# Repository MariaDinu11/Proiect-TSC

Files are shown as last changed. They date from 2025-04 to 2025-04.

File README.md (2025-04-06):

# Proiect-TSC

  OpenBook E-Reader
OpenBook este un e-book reader open source si accesibil, proiectat pentru a oferi o experiență bună de citire la un preț competitiv.



## Bill of Materials (BOM)

| Nr. | Componenta | Descriere | Cantitate | Link achizitie | Datasheet |
|-----|---|---|---|---|---|
| 1 | ESP32-C6-WROOM-1-N8 | Modul WiFi/Bluetooth/Zigbee | 1 | [Model](https://www.snapeda.com/parts/ESP32-C6-WROOM-1-N8/Espressif+Systems/view-part/?ref=eda) | [Datasheet](https://www.espressif.com/sites/default/files/documentation/esp32-c6_datasheet_en.pdf) |
| 2 | W25Q512JVEIQ | Memorie Flash NOR 64MB | 1 | [Model](https://www.snapeda.com/parts/W25Q512JVEIQ/Winbond+Electronics/view-part/?ref=eda) | [Datasheet](https://www.winbond.com/resource-files/W25Q512JV%20RevI%2005132020%20Plus.pdf) |
| 3 | DS3231SN# | Modul RTC de inalta precizie | 1 | [Model](https://www.snapeda.com/parts/DS3231SN%23/Analog+Devices/view-part/?ref=eda) | [Datasheet](https://datasheets.maximintegrated.com/en/ds/DS3231.pdf) |
| 4 | MAX17048G+T10 | Controlor pentru monitorizarea bateriei | 1 | [Model](https://www.snapeda.com/parts/MAX17048G+T10/Analog+Devices/view-part/?ref=eda) | [Datasheet](https://datasheets.maximintegrated.com/en/ds/MAX17048-MAX17049.pdf) |
| 5 | BME688 | Senzor integrat de mediu | 1 | [Model](https://www.snapeda.com/parts/BME680/Bosch/view-part/?welcome=home) | [Datasheet](https://www.bosch-sensortec.com/media/boschsensortec/downloads/datasheets/bst-bme688-ds000.pdf) |
| 6 | MCP73831 | Controler de incarcare baterie Li-Po | 1 | [Model](https://www.mouser.co.uk/ProductDetail/Microchip-Technology/MCP73831T-5ACI-OT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) | [Datasheet](https://ww1.microchip.com/downloads/en/DeviceDoc/20001984g.pdf) |
| 7 | BD5229G-TR | Detector de tensiune cu timp de intarziere | 1 | [Model](https://componentsearchengine.com/part-view/BD5229G-TR/ROHM%20Semiconductor) | [Datasheet](https://fscdn.rohm.com/en/products/databook/datasheet/ic/power/voltage_detector/bd52xxg-e.pdf) |
| 8 | PFMF.050.1 | Conector USB Type-C | 1 | [Model](https://www.mouser.com/ProductDetail/Amphenol-FCI/PFMF0501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) | [Datasheet](https://cdn.amphenol-cs.com/media/wysiwyg/files/drawing/pfmf.pdf) |
| 9 | USBLC6-2SC6Y | Protectie ESD pentru linii USB | 1 | [Model](https://www.snapeda.com/parts/USBLC6-2SC6Y/STMicroelectronics/view-part/?ref=eda) | [Datasheet](https://www.st.com/resource/en/datasheet/usblc6-2.pdf) |
| 10 | 112A-TAAR-R03 | Slot pentru card microSD | 1 | [Model](https://www.mouser.com/ProductDetail/Attend/112A-TAAR-R03?qs=sGAEpiMZZMsg%2By7HCF96QHhTCuZhYGBTHJ9NEpPMzZc%3D) | [Datasheet](https://www.attend.com.tw/sites/default/files/2022-05/112A-TAAR-R03.pdf) |
| 11 | FH34SRJ-24S-0.5SH | Conector pentru ecran e-paper | 1 | [Model](https://www.hirose.com/product/p/CL0684-0832-7-99) | [Datasheet](https://www.hirose.com/product/document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) |
| 12 | DMG2305UX-7 | Tranzistor MOSFET-P 20V/4.2A | 1 | [Model](https://www.diodes.com/part/view/DMG2305UX) | [Datasheet](https://www.diodes.com/assets/Datasheets/DMG2305UX.pdf) |
| 13 | SI1308EDL-T1-GE3 | Tranzistor MOSFET-N 30V/1.5A | 1 | [Model](https://www.snapeda.com/parts/SI1308EDL-T1-GE3/Vishay+Siliconix/view-part/?ref=snap) | [Datasheet](https://www.vishay.com/docs/68732/si1308edl.pdf) |
| 14 | SD0805S020S1R0 | Inductor 1.0µH | 1 | [Model](https://eu.mouser.com/ProductDetail/KYOCERA-AVX/SD0805S020S1R0?qs=jCA%252BPfw4LHbpkAoSnwrdjw%3D%3D) | [Datasheet](http://datasheets.avx.com/schottky.pdf) |
| 15 | MBR0530 | Dioda Schottky 30V/500mA | 3 | [Model](https://www.snapeda.com/parts/MBR0530/Onsemi/view-part/?ref=eda) | [Datasheet](https://www.onsemi.com/pdf/datasheet/mbr0520lt1-d.pdf) |
| 16 | PGB1010603MR | Dioda TVS pentru protectie ESD | 5 | [Model](https://www.snapeda.com/parts/PGB1010603MR/Littelfuse/view-part/?ref=eda) | [Datasheet](https://www.littelfuse.com/media?itemid=3d1e98b7-4d37-463c-9380-c56c83b11c3c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) |
| 17 | CPH3225A | Cristal RTC 32.768kHz | 1 | [Model](https://www.snapeda.com/parts/CPH3225A/Seiko+Instruments/view-part/?ref=eda) | [Datasheet](https://www.sii.co.jp/en/quartz/files/2021/03/CPH3225A_E.pdf) |
| 18 | XC6220A331MR-G | Regulator LDO de tensiune 3.3V | 1 | [Model](https://www.torexsemi.com/products/voltage-regulators/ldo-regulators/xc6220/) | [Datasheet](https://www.torexsemi.com/file/xc6220/XC6220.pdf) |
| 19 | Buton tactil | Butoane pentru Reset, Boot, Change | 3 | [Model](https://industry.panasonic.com/ww/products/industrial-devices/mechanical-components/switches/light-touch-switches/light-touch-switches/evqpuj02k) | [Datasheet](https://industry.panasonic.com/ww/components/devices/mechanical-components/switches/light-touch-switches/products/evqpuj02k) |
| 20 | LEDs SMD 0603 | LED indicator | 1 | [Model](https://www.snapeda.com/parts/KP-1608SURCK/Kingbright/view-part/?ref=search&t=LED%200603) | [Datasheet](https://www.kingbrightusa.com/images/catalog/SPEC/APHHS1608LSURKCGKC.pdf) |
| 21 | QWIIC_RIGHT_ANGLE | Conector I²C Qwiic | 1 | [Model](https://www.sparkfun.com/products/14417) | [Datasheet](https://cdn.sparkfun.com/assets/1/4/d/8/3/Qwiic_Connector_Datasheet.pdf) |
| 22 | Rezistor 10K | SMD 0402 | 12 | [Model](https://componentsearchengine.com/part-view/R0402%201%25%20100%20K%20(RC0402FR-07100KL)/YAGEO) | - |
| 23 | Rezistor 5.1K | SMD 0402 | 2 | [Model](https://www.yageo.com/en/Product/resistors) | - |
| 24 | Rezistor 2K | SMD 0402 | 1 | [Model](https://www.yageo.com/en/Product/resistors) | - |
| 25 | Rezistor 2.2 | SMD 0402 | 1 | [Model](https://www.yageo.com/en/Product/resistors) | - |
| 26 | Rezistor 200 | SMD 0402 | 1 | [Model](https://www.yageo.com/en/Product/resistors) | - |
| 27 | Rezistor 100K | SMD 0402 | 1 | [Model](https://www.yageo.com/en/Product/resistors) | - |
| 28 | Rezistor 15 | SMD 0402 | 1 | [Model](https://www.yageo.com/en/Product/resistors) | - |
| 29 | Rezistor 0.47 | SMD 0402 | 1 | [Model](https://www.yageo.com/en/Product/resistors) | - |
| 30 | Capacitor 100nF | SMD 0402 | 10 | [Model](https://componentsearchengine.com/part-view/CC0402MRX5R5BB106/YAGEO) | - |
| 31 | Capacitor 4.7µF | SMD 0402 | 5 | [Model](https://www.yageo.com/en/Product/mlcc) | - |
| 32 | Capacitor 1µF | SMD 0402 | 10 | [Model](https://www.yageo.com/en/Product/mlcc) | - |
| 33 | Capacitor 1µF/50V | SMD 0402 | 10 | [Model](https://www.yageo.com/en/Product/mlcc) | - |
| 34 | Capacitor 10µF | SMD 0402 | 1 | [Model](https://www.yageo.com/en/Product/mlcc) | - |
| 35 | Capacitor 100µF TANT | SMD CT3528 | 1 | [Model](https://a360.co/4iZy6AA) | - |
| 36 | Test pads | Puncte de testare TP20R | 17 | [Model](https://www.keyelco.com/product.cfm/product_id/1543) | - |
| 37 | SMD Solder Jumper | Jumper SMD | 1 | [Model](https://grabcad.com/library/solder-jumpers-1) | - |

## Functionalitatea Hardware

### Componente Principale

1. **Microcontroller ESP32-C6**
   - Procesor RISC-V cu 8MB Flash
   - WiFi 6 (802.11ax), Bluetooth 5, suport Zigbee si Thread
   - Management optimizat al energiei pentru durata de viata a bateriei

2. **Interfata Display E-Paper**
   - Conectata prin interfata SPI si semnale de control dedicate
   - Circuit special pentru generarea tensiunilor e-paper
   - Consum de energie aproape zero in stare statica

3. **Sistem de Stocare**
   - Flash extern 64MB (W25Q512JVEIQ) pentru fonturi si elemente UI
   - Slot card MicroSD pentru biblioteca extinsa de carti

4. **Management Energie**
   - Circuit incarcare baterie LiPo folosind MCP73831
   - Regulator de tensiune XC6220A331MR-G pentru 3.3V stabil
   - MAX17048G+T10 pentru monitorizare precisa a nivelului bateriei
   - Moduri deep sleep pentru durata extinsa de viata a bateriei

5. **Periferice Auxiliare**
   - Senzor de mediu BME688 (temperatura, umiditate, calitatea aerului)
   - Modul RTC DS3231SN de precizie inalta
   - Conector Qwiic/Stemma QT pentru expansiune
   - Trei butoane tactile pentru navigare

### Tabel detaliat al utilizarii pinilor

| Pin ESP32-C6 | Functie | Conectat la | Justificare |
|---|---|---|---|
| GPIO 0 | IO/BOOT | Buton BOOT | Pin special cu functie de Boot necesar pentru intrarea in modul de programare |
| GPIO 1 | FLASH_CS | Memorie Flash W25Q512JVEIQ | Chip Select pentru memoria Flash externa, pozitionat logic in apropierea celorlalti pini SPI |
| GPIO 2 | EN | Circuit supervisor BD5229G-TR | Semnal de Enable pentru microcontroller, controlat de supervizorul de tensiune |
| GPIO 3 | SDA | Magistrala I²C | Linie de date pentru interfata I²C care conecteaza senzorul BME688, RTC-ul si monitorul bateriei |
| GPIO 4 | SCL | Magistrala I²C | Linie de clock pentru interfata I²C, cu rezistori pull-up adecvati |
| GPIO 5 | MOSI | Interfata SPI (Flash, E-Paper, SD) | Master Out Slave In pentru comunicatiile SPI, folosit pentru toate dispozitivele SPI |
| GPIO 6 | MISO | Interfata SPI (Flash, SD) | Master In Slave Out pentru comunicatiile SPI, primeste date de la perifericele SPI |
| GPIO 7 | SCK | Interfata SPI (Flash, E-Paper, SD) | Clock pentru interfata SPI, sincronizeaza toate dispozitivele SPI |
| GPIO 8 | USB_D+ | Interfata USB | Linie de date pozitiva USB, conectata la conectorul USB-C prin protectie ESD |
| GPIO 9 | USB_D- | Interfata USB | Linie de date negativa USB, conectata la conectorul USB-C prin protectie ESD |
| GPIO 10 | EPD_CS | E-Paper Display | Chip Select pentru display-ul e-paper, activeaza comunicatia SPI cu acesta |
| GPIO 11 | SS_SD | Card SD | Chip Select pentru cardul SD, permite selectarea independenta a cardului pe magistrala SPI comuna |
| GPIO 12 | EPD_DC | E-Paper Display | Data/Command pentru e-paper, diferentiaza intre comenzi si date pe magistrala SPI |
| GPIO 13 | EPD_RST | E-Paper Display | Reset pentru e-paper, permite reinitializarea hardware a display-ului |
| GPIO 15 | INT_RTC | Modul RTC DS3231SN | Interrupt de la RTC, permite trezirea din sleep la alarme sau evenimente temporizate |
| GPIO 16 | TXD0 | UART Debug/Test | Transmit pentru UART, folosit pentru debug si diagnosticare |
| GPIO 17 | RXD0 | UART Debug/Test | Receive pentru UART, folosit pentru debug si diagnosticare |
| GPIO 18 | EPD_BUSY | E-Paper Display | Semnal Busy de la e-paper, indica cand display-ul proceseaza date |
| GPIO 19 | IO/CHANGE | Buton CHANGE | Intrare pentru butonul de schimbare a optiunilor, cu pull-up intern |
| GPIO 21-23 | Test Pads | Puncte de testare | Pini disponibili pentru testare si diagnosticare |

## Decizii si modificari de design
* Am pozitionat componentele principale conform specificatiilor pentru a asigura compatibilitatea perfecta intre dimensiunile PCB-ului si carcasa. Bateria a fost plasata in spatiul ramas disponibil.
* Am creat planuri de masa atat pe straturile superioare cat si inferioare pentru a imbunatati integritatea semnalului si a reduce zgomotul electromagnetic.
* Rutarea a fost realizata pe ambele straturi, insa am plasat traseele de putere exclusiv pe stratul superior pentru a evita utilizarea via-urilor, conform recomandarilor.
* Am modificat dimensiunile pad-urilor pentru diode la 35 x 190 mil pentru a imbunatati procesul de fabricatie si fiabilitatea contactelor electrice.
* Pentru circuitul MAX17048G+T10, am ajustat latimea pad-urilor pentru a corespunde cu latimea traseului VBAT de 0.3 mm, asigurand o rutare consecventa si un layout mai echilibrat.



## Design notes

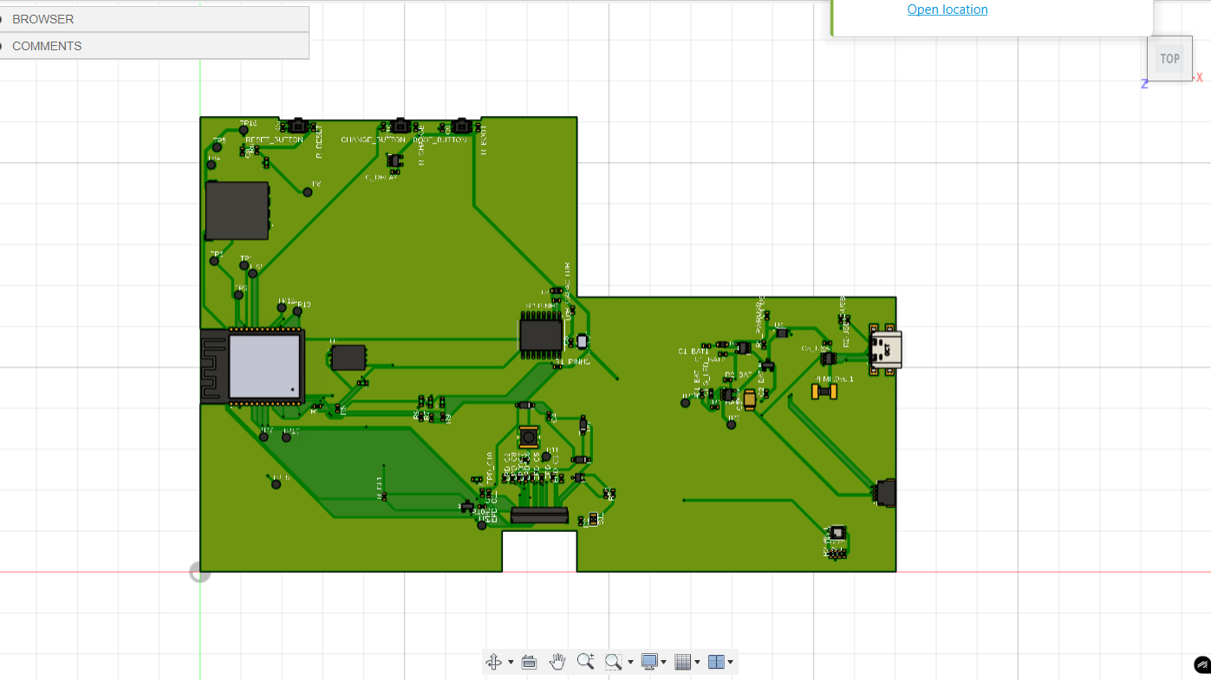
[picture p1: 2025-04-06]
Images/Screenshot 2025-04-06 195034.png

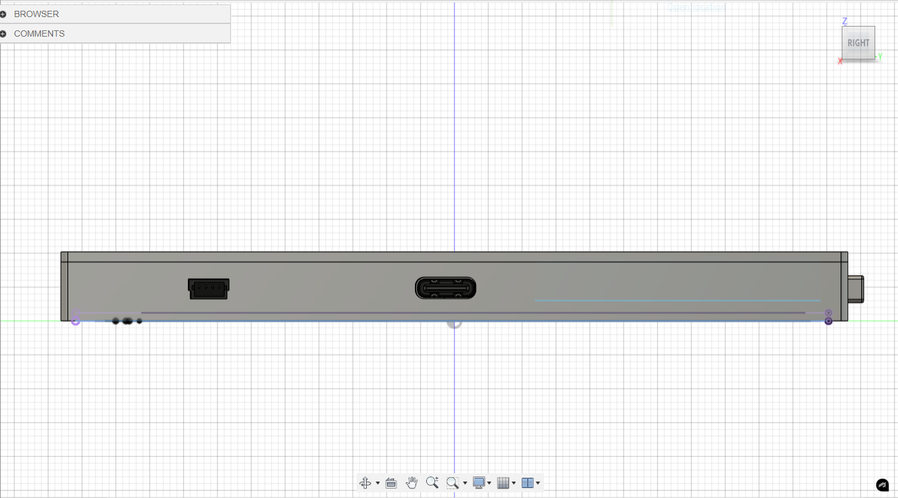
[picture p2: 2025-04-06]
Images/Screenshot 2025-04-06 195138.png

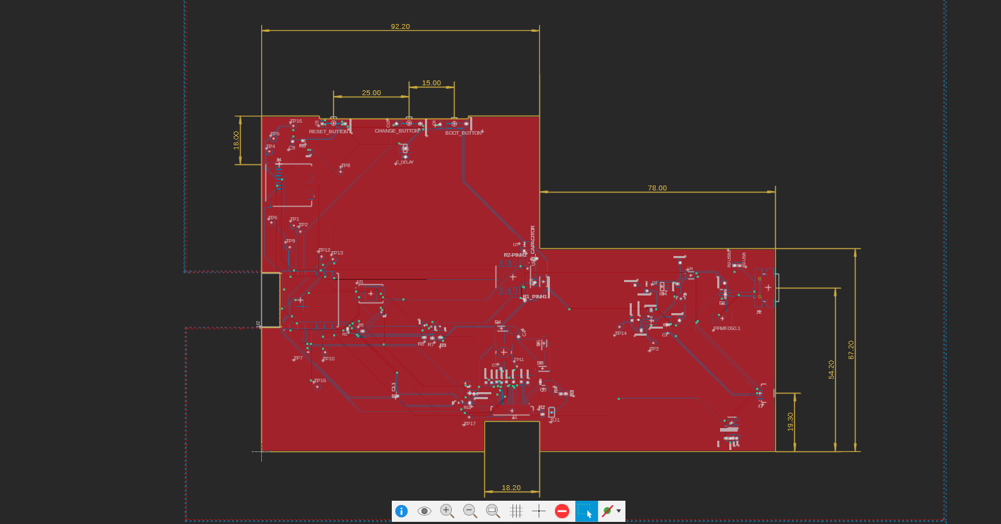
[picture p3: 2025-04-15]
Images/Screenshot 2025-04-15 214132.png

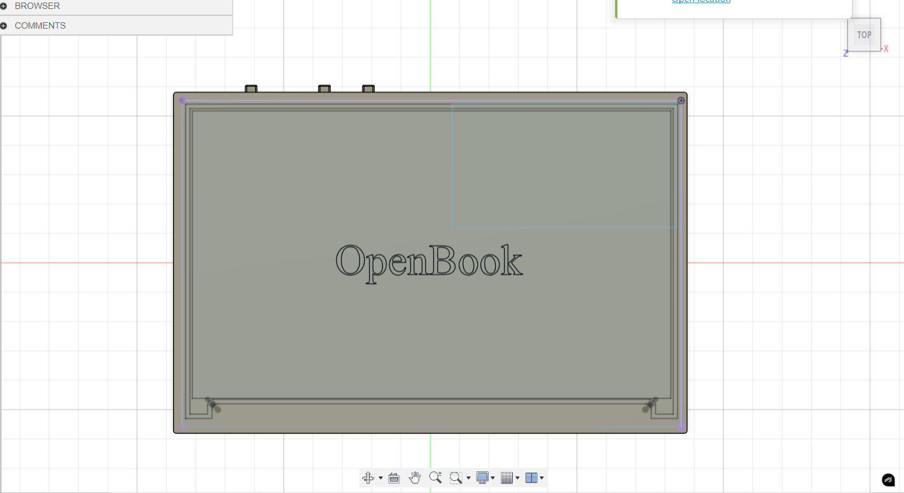
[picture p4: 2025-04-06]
Images/Screenshot 2025-04-06 195115.png

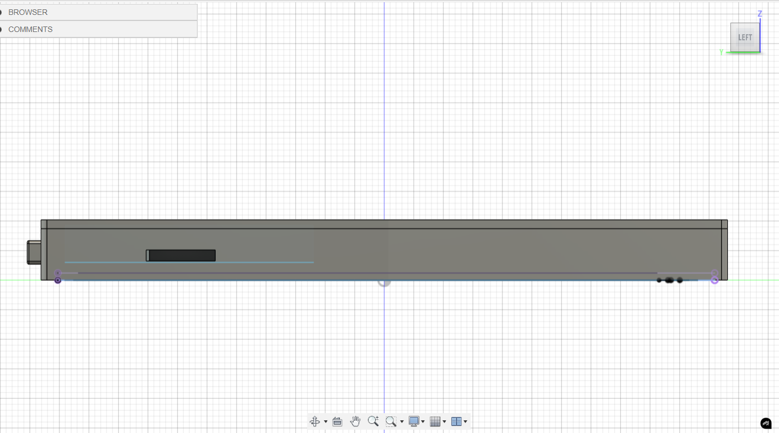
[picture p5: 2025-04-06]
Images/Screenshot 2025-04-06 195158.png

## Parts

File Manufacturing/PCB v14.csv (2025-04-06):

Qty | Value | Device | Package | Parts | Description | ARROW_PART_NUMBER | ARROW_PRICE-STOCK | AVAILABILITY | CENTROID_NOT_SPECIFIED | CHECK_PRICES | COPYRIGHT | DATASHEET | DESCRIPTION | DIGIKEY_DESCRIPTION | DIGIKEY_PART_NUMBER | HEIGHT | LEAD_FREE | MANUFACTURER_NAME | MANUFACTURER_PART_NUMBER | MF | MFR_NAME | MOUSER_PART_NUMBER | MOUSER_PRICE-STOCK | MOUSER_TESTING_PART_NUMBER | MOUSER_TESTING_PRICE-STOCK | MP | MPN | PACKAGE | POPULARITY | PREFIX | PRICE | PROD_ID | PURCHASE-URL | ROHS | SNAPEDA_LINK | SPICEMODEL | SPICEPREFIX | TEMPERATURE_RANGE_HIGH | TEMPERATURE_RANGE_LOW | TP_SIGNAL_NAME | VALUE | LSCS Part number
1 |  | ADAFRUIT_LEDCHIP-LED0603 | ADAFRUIT_CHIP-LED0603 | CHG_LED | LED
1 |  | ESP32_WROVER_EAGLE-LTSPICE_RR0402 | ESP32_WROVER_EAGLE-LTSPICE_R0402 | R2 | RESISTOR, European symbol |  |  |  |  |  |  |  |  |  |  |  |  |  |  |  |  |  |  |  |  |  |  |  |  |  |  |  |  |  |  | NONE | R
1 |  | SJ | SJ | SJ1 | SMD solder JUMPER |  |  |  |  |  |  |  |  |  |  |  |  |  |  |  |  |  |  |  |  |  |  |  | 3
1 | 0.47 | ESP32_WROVER_EAGLE-LTSPICE_RR0402 | ESP32_WROVER_EAGLE-LTSPICE_R0402 | R3 | RESISTOR, European symbol |  |  |  |  |  |  |  |  |  |  |  |  |  |  |  |  |  |  |  |  |  |  |  |  |  |  |  |  |  |  | NONE | R
1 | 100k | ESP32_WROVER_EAGLE-LTSPICE_RR0402 | ESP32_WROVER_EAGLE-LTSPICE_R0402 | R1_PWRUSB | RESISTOR, European symbol |  |  |  |  |  |  |  |  |  |  |  |  |  |  |  |  |  |  |  |  |  |  |  |  |  |  |  |  |  |  | NONE | R
8 | 100nF | EAGLE-LTSPICE_CC0402 | EAGLE-LTSPICE_C0402 | C1, C2, C4_USB, C6, C8, C9, C10, C_DELAY | CAPACITOR, European symbol |  |  |  |  |  |  |  |  |  |  |  |  |  |  |  |  |  |  |  |  |  |  |  |  |  |  |  |  |  |  | NONE | C
1 | 100uF TANT | RCL_CPOL-EUCT3528 | RCL_CT3528 | C3 | POLARIZED CAPACITOR, European symbol |  |  |  |  |  |  |  |  |  |  |  |  |  |  |  |  |  |  |  |  |  |  |  | 0 |  |  |  |  |  |  |  | C
10 | 10K | ESP32_WROVER_EAGLE-LTSPICE_RR0402 | ESP32_WROVER_EAGLE-LTSPICE_R0402 | R1_PINH, R2-PINH, R5, R6, R7, R8, R9, R10, R_CHANGE, R_CL1 | RESISTOR, European symbol |  |  |  |  |  |  |  |  |  |  |  |  |  |  |  |  |  |  |  |  |  |  |  |  |  |  |  |  |  |  | NONE | R
6 | 10k | ESP32_WROVER_EAGLE-LTSPICE_RR0402 | ESP32_WROVER_EAGLE-LTSPICE_R0402 | R1, R1_PINH1, R2-PINH1, R4, R_BOOT, R_RESET | RESISTOR, European symbol |  |  |  |  |  |  |  |  |  |  |  |  |  |  |  |  |  |  |  |  |  |  |  |  |  |  |  |  |  |  | NONE | R
1 | 10uF | EAGLE-LTSPICE_CC0402 | EAGLE-LTSPICE_C0402 | C7 | CAPACITOR, European symbol |  |  |  |  |  |  |  |  |  |  |  |  |  |  |  |  |  |  |  |  |  |  |  |  |  |  |  |  |  |  | NONE | C
1 | 112A-TAAR-R03_ATTEND | 112A-TAAR-R03_ATTEND | 112ATAARR03ATTEND | J4 | Micro SD Card Socket, Push-Push Type, Top Mount, SMT, H=1.83mm, 10u |  |  |  |  |  |  |  | Micro SD Card Socket | Push-Push Type | Top Mount | SMT | H=1.83mm | 10u |  |  | 1.9mm |  | ATTEND | 112A-TAAR-R03 ATTEND
1 | 15 | ESP32_WROVER_EAGLE-LTSPICE_RR0402 | ESP32_WROVER_EAGLE-LTSPICE_R0402 | R_CAPACITOR | RESISTOR, European symbol |  |  |  |  |  |  |  |  |  |  |  |  |  |  |  |  |  |  |  |  |  |  |  |  |  |  |  |  |  |  | NONE | R
1 | 1uF | EAGLE-LTSPICE_CC0402 | EAGLE-LTSPICE_C0402 | C5 | CAPACITOR, European symbol |  |  |  |  |  |  |  |  |  |  |  |  |  |  |  |  |  |  |  |  |  |  |  |  |  |  |  |  |  |  | NONE | C
10 | 1uF/50V | EAGLE-LTSPICE_CC0402 | EAGLE-LTSPICE_C0402 | EPD_C1, EPD_C2, EPD_C5, EPD_C6, EPD_C7, EPD_C8, EPD_C9, EPD_C10, EPD_C11, EPD_C12 | CAPACITOR, European symbol |  |  |  |  |  |  |  |  |  |  |  |  |  |  |  |  |  |  |  |  |  |  |  |  |  |  |  |  |  |  | NONE | C
1 | 200 | ESP32_WROVER_EAGLE-LTSPICE_RR0402 | ESP32_WROVER_EAGLE-LTSPICE_R0402 | R1_BAT | RESISTOR, European symbol |  |  |  |  |  |  |  |  |  |  |  |  |  |  |  |  |  |  |  |  |  |  |  |  |  |  |  |  |  |  | NONE | R
2 | 20V/4.2A/52mO/1.4W | ESP32_WROVER_SPARKFUN-DISCRETESEMI_MOSFET_PCH-DMG2305UX-7 | ESP32_WROVER_SPARKFUN-DISCRETESEMI_SOT23-3 | Q1, Q2 | P-channel MOSFETs |  |  |  |  |  |  |  |  |  |  |  |  |  |  |  |  |  |  |  |  |  |  |  |  |  |  | TRAN-14388 |  |  |  |  |  |  |  |  | 20V/4.2A/52mO/1.4W
1 | 2K | ESP32_WROVER_EAGLE-LTSPICE_RR0402 | ESP32_WROVER_EAGLE-LTSPICE_R0402 | R2_BAT | RESISTOR, European symbol |  |  |  |  |  |  |  |  |  |  |  |  |  |  |  |  |  |  |  |  |  |  |  |  |  |  |  |  |  |  | NONE | R
1 | 4.7uF | EAGLE-LTSPICE_CC0402 | EAGLE-LTSPICE_C0402 | C5_USB | CAPACITOR, European symbol |  |  |  |  |  |  |  |  |  |  |  |  |  |  |  |  |  |  |  |  |  |  |  |  |  |  |  |  |  |  | NONE | C
4 | 47uF | EAGLE-LTSPICE_CC0402 | EAGLE-LTSPICE_C0402 | C1_BAT, C1_BAT1, C1_BAT2, C2_BAT | CAPACITOR, European symbol |  |  |  |  |  |  |  |  |  |  |  |  |  |  |  |  |  |  |  |  |  |  |  |  |  |  |  |  |  |  | NONE | C
1 | 47uF/25V | EAGLE-LTSPICE_CC0402 | EAGLE-LTSPICE_C0402 | C4 | CAPACITOR, European symbol |  |  |  |  |  |  |  |  |  |  |  |  |  |  |  |  |  |  |  |  |  |  |  |  |  |  |  |  |  |  | NONE | C
2 | 5k1 | ESP32_WROVER_EAGLE-LTSPICE_RR0402 | ESP32_WROVER_EAGLE-LTSPICE_R0402 | R2-USB, R2-USB1 | RESISTOR, European symbol |  |  |  |  |  |  |  |  |  |  |  |  |  |  |  |  |  |  |  |  |  |  |  |  |  |  |  |  |  |  | NONE | R
1 | 68uH | 744043680IND_4828-WE-TPC_WRE | IND_4828-WE-TPC_WRE | L1 |  |  |  |  |  |  | Copyright (C) 2024 Ultra Librarian. All rights reserved. |  |  |  |  |  |  |  | 744043680 |  | Wurth Electronics
1 | BD5229G-TR | BD5229G-TR | SOT95P280X125-5N | IC1 | Voltage Detector with Adjustable Delay Time: CMOS processes are utilized to develop high precision, low current consumption CMOS reset ICs that allow arbitrary setting of the delay time. The extensive lineup includes both Nch Open Drain and CMOS output types in a wide range of detection voltages (from 2.3V to 6.0V, in 0.1V steps), enabling selection of the ideal solution based on customer requirements. In addition, the entire series is of course both lead-free and RoHS-compliant. |  |  |  |  |  |  |  | Voltage Detector with Adjustable Delay Time: CMOS processes are utilized to develop high precision | low current consumption CMOS reset ICs that allow arbitrary setting of the delay time. The extensive lineup includes both Nch Open Drain and CMOS output types in a wide range of detection voltages (from 2.3V to 6.0V | in 0.1V steps) | enabling selection of the ideal solution based on customer requirements. In addition | the entire series is of course both lead-free and RoHS-compliant. |  |  | 1.25mm |  | ROHM Semiconductor | BD5229G-TR |  |  | 755-BD5229G-TR | https://www.mouser.co.uk/ProductDetail/ROHM-Semiconductor/BD5229G-TR?qs=4kLU8WoGk0vvnhrrYwdszw%3D%3D
1 | BME688 | ESP32_WROVER_BME680_BME680 | ESP32_WROVER_BME680_PSON80P300X300X100-8N | SENSOR2 | Integrated Environmental Unit |  |  | Unavailable |  |  |  |  | Integrated Environmental Unit |  |  |  |  |  |  | Bosch Sensortec |  |  |  |  |  | BME680 |  | LGA-8 Bosch Tools |  |  | None
3 | BUTTON_CUSYOMV1 | BUTTON_CUSYOMV1 | MYBUTTON | BOOT_BUTTON, CHANGE_BUTTON, RESET_BUTTON
1 | CPH3225A | CPH3225A | CAPCP3225X100N | C10_SUPERCAP | Cap 0.011F 3.3V 1210 Flat Check availability |  |  | Not in stock |  | https://www.snapeda.com/parts/CPH3225A/Seiko+Instruments/view-part/?ref=eda |  |  | 11 mF (EDLC) Supercapacitor 3.3 V 1210 (3225 Metric) - - |  |  |  |  |  |  | Seiko Instruments |  |  |  |  |  | CPH3225A |  | 1210 Seiko |  |  | None |  | https://www.snapeda.com/api/url_track_click_mouser/?unipart_id=562593&manufacturer=Seiko Instruments&part_name=CPH3225A&search_term=None |  | https://www.snapeda.com/parts/CPH3225A/Seiko+Instruments/view-part/?ref=snap
1 | DS3231SN# | DS3231SN# | SOIC127P1032X265-16N | U3 | Real Time Clock Serial 16-Pin SOIC W T/R Check availability |  |  | In Stock |  | https://www.snapeda.com/parts/DS3231SN%23/Analog+Devices/view-part/?ref=eda |  |  | Extremely Accurate I²C-Integrated RTC/TCXO/Crystal |  |  |  |  |  |  | Analog Devices |  |  |  |  |  | DS3231SN# |  | SOIC-16 Maxim |  |  | None |  | https://www.snapeda.com/api/url_track_click_mouser/?unipart_id=99048&manufacturer=Analog Devices&part_name=DS3231SN#&search_term=None |  | https://www.snapeda.com/parts/DS3231SN%23/Analog+Devices/view-part/?ref=snap
1 | ESP32-C6-WROOM-1-N8 | ESP32-C6-WROOM-1-N8 | XCVR_ESP32-C6-WROOM-1-N8 | U2 | Check availability |  |  | In Stock |  | https://www.snapeda.com/parts/ESP32-C6-WROOM-1-N8/Espressif+Systems/view-part/?ref=eda |  |  | Multiprotocol Modules ESP32-C6 module | Wi-Fi 6 in 2.4 GHz band | Bluetooth 5 | Zigbee 3.0 and Thread. ESP34-WROOM Compatible - ENGINEERING SAMPLE |  |  |  |  |  |  | Espressif Systems |  |  |  |  |  | ESP32-C6-WROOM-1-N8 |  | None |  |  | None |  |  |  | https://www.snapeda.com/parts/ESP32-C6-WROOM-1-N8/Espressif+Systems/view-part/?ref=snap
1 | ESP32C6_VARISTORCN1812 | ESP32C6_VARISTORCN1812 | ESP32C6_VARISTOR_CT/CN1812 | PFMF.050.1 | VARISTOR |  |  |  |  |  |  |  |  |  |  |  |  |  |  |  |  |  |  |  |  |  |  |  | 0
1 | ESP32_WROVER_SPARKFUN-IC-POWER_MCP73831 | ESP32_WROVER_SPARKFUN-IC-POWER_MCP73831 | ESP32_WROVER_SPARKFUN-IC-POWER_SOT23-5 | MCP73831 | MCP73831T Li-Ion, Li-Pol Controller |  |  |  |  |  |  |  |  |  |  |  |  |  |  |  |  |  |  |  |  |  |  |  |  |  |  | IC-09995
1 | FH34SRJ-24S-0.5SH_99_ | FH34SRJ-24S-0.5SH_99_ | FH34SRJ24S05SH99 | J1 | (0.50mm) Surface Mount, Right Angle |  |  |  |  |  |  |  | 24 Position FFC | FPC Connector Contacts | (0.50mm) Surface Mount | Right Angle |  |  | 1.1mm |  | Hirose | FH34SRJ-24S-0.5SH(99) |  |  | 798-FH34SRJ24S05SH99 | https://www.mouser.co.uk/ProductDetail/Hirose-Connector/FH34SRJ-24S-0.5SH99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
1 | MAX17048G+T10 | MAX17048G+T10 | SON50P200X200X80-9N | U4 | Check availability |  |  | In Stock |  | https://www.snapeda.com/parts/MAX17048G+T10/Analog+Devices/view-part/?ref=eda |  |  | 3µA 1-Cell/2-Cell Fuel Gauge with ModelGauge |  |  |  |  |  |  | Analog Devices |  |  |  |  |  | MAX17048G+T10 |  | TDFN-8 Maxim |  |  | None |  | https://www.snapeda.com/api/url_track_click_mouser/?unipart_id=329239&manufacturer=Analog Devices&part_name=MAX17048G+T10&search_term=None |  | https://www.snapeda.com/parts/MAX17048G+T10/Analog+Devices/view-part/?ref=snap
3 | MBR0530 | MBR0530 | SOD3716X135N | D3, D4, D5 | ON SEMICONDUCTOR - MBR0530 - DIODE, SCHOTTKY, 0.5A, 30V, SOD-123 |  |  | In Stock |  | https://www.snapeda.com/parts/MBR0530/Onsemi/view-part/?ref=eda |  |  | Diode Schottky 30 V 500mA Surface Mount SOD-123 |  |  |  |  |  |  | ON Semiconductor |  |  |  |  |  | MBR0530 |  | SOD-123-2 ON Semiconductor |  |  | None |  | https://www.snapeda.com/api/url_track_click_mouser/?unipart_id=179458&manufacturer=ON Semiconductor&part_name=MBR0530&search_term=None |  | https://www.snapeda.com/parts/MBR0530/Onsemi/view-part/?ref=snap
6 | PGB1010603MR | PGB1010603MR | DIOC1608X36N | D6, D8, D9, D10, D11, D12 | Check availability |  |  | In Stock |  | https://www.snapeda.com/parts/PGB1010603MR/Littelfuse/view-part/?ref=eda |  |  | 150V (Typ) Clamp - Ipp Tvs Diode Surface Mount 0603 (1608 Metric) |  |  |  |  |  |  | Littelfuse Inc. |  |  |  |  |  | PGB1010603MR |  | 0603 Littelfuse Inc. |  |  | None |  | https://www.snapeda.com/api/url_track_click_mouser/?unipart_id=5659453&manufacturer=Littelfuse Inc.&part_name=PGB1010603MR&search_term=None |  | https://www.snapeda.com/parts/PGB1010603MR/Littelfuse/view-part/?ref=snap
1 | QWIIC_RIGHT_ANGLE | QWIIC_CONNECTORJS-1MM | JST04_1MM_RA | J3 | SparkFun I2C Standard Qwiic Connector |  |  |  |  |  |  |  |  |  |  |  |  |  |  |  |  |  |  |  |  |  |  |  |  |  |  | CONN-13694 |  |  |  |  |  |  |  |  | QWIIC_RIGHT_ANGLE
1 | SAMACSYS_PARTS_USB4110-GF-A | SAMACSYS_PARTS_USB4110-GF-ASAM | SAMACSYS_PARTS_USB4110GFA | J2 | CONN USB 2.0 TYPE-C R/A SMT
2 | SD0805S020S1R0 | ESP32_WROVER_AVX---SD0805S020S1R0_AVX_SD0805S020S1R0_0_0AVX_SD0805S020S1R0_0_0 | ESP32_WROVER_AVX---SD0805S020S1R0_AVX_SD0805S020S1R0_0 | D2, D7 | Schottky Barrier Rectifier Diode |  |  |  | No |  |  | http://datasheets.avx.com/schottky.pdf |  | DIODE SCHOTTKY 20V 1A 0805 | 478-7800-1-ND |  | yes |  |  | AVX |  | 581-SD0805S020S1R0 |  |  |  |  |  | 0805 (2012 metric) |  | D |  |  |  | yes |  |  |  | +125°C | -55°C
1 | SI1308EDL-T1-GE3 | SI1308EDL-T1-GE3 | SOT65P210X110-3N | Q3 | MOSFET N-Ch 30V 1.5A TrenchFET SC70 Vishay Si1308EDL-T1-GE3 N-channel MOSFET Transistor, 1.5 A, 30 V, 3-Pin SC-70 |  |  | In Stock |  | https://www.snapeda.com/parts/SI1308EDL-T1-GE3/Vishay+Siliconix/view-part/?ref=eda |  |  | Si1308EDL-T1-GE3 N-channel MOSFET Transistor | 1.5 A | 30 V | 3-Pin SC-70 | Siliconix / Vishay SI1308EDL-T1-GE3 |  |  |  |  |  |  | Vishay Siliconix |  |  |  |  |  | SI1308EDL-T1-GE3 |  | SOT-323 Vishay Semiconductor |  |  | None |  | https://www.snapeda.com/api/url_track_click_mouser/?unipart_id=274603&manufacturer=Vishay Siliconix&part_name=SI1308EDL-T1-GE3&search_term=None |  | https://www.snapeda.com/parts/SI1308EDL-T1-GE3/Vishay+Siliconix/view-part/?ref=snap
17 | TPTP20R | TPTP20R | TP20R | TP1, TP2, TP3, TP4, TP5, TP6, TP7, TP8, TP9, TP10, TP11, TP12, TP13, TP14, TP15, TP16, TP17 | Test pad |  |  |  |  |  |  |  |  |  |  |  |  |  |  |  |  |  |  |  |  |  |  |  | 2
1 | USBLC6-2SC6Y | USBLC6-2SC6Y | SOT95P280X145-6N | D1 | Low Cap. ESD Protection Auto SOT-23-6 STMicroelectronics USBLC6-2SC6Y, Dual Uni-Directional TVS Diode Array, 6-Pin SOT-23 |  |  | In Stock |  | https://www.snapeda.com/parts/USBLC6-2SC6Y/STMicroelectronics/view-part/?ref=eda |  |  | 17V Clamp 5A (8/20µs) Ipp Tvs Diode Surface Mount SOT-23-6 |  |  |  |  |  |  | STMicroelectronics |  |  |  |  |  | USBLC6-2SC6Y |  | SOT-23-6 STMicroelectronics |  |  | None |  |  |  | https://www.snapeda.com/parts/USBLC6-2SC6Y/STMicroelectronics/view-part/?ref=snap
1 | W25Q512JVEIQ | W25Q512JVEIQ | SON127P600X800X80-9N | U1 | Check availability |  |  | In Stock |  | https://www.snapeda.com/parts/W25Q512JVEIQ/Winbond+Electronics/view-part/?ref=eda |  |  | FLASH - NOR Memory IC 512Mb (64M x 8) SPI - Quad I/O 133 MHz 8-WSON (8x6) |  |  |  |  |  |  | Winbond Electronics |  |  |  |  |  | W25Q512JVEIQ |  | Package |  |  | None |  |  |  | https://www.snapeda.com/parts/W25Q512JVEIQ/Winbond+Electronics/view-part/?ref=snap
1 | XC6220A331MR-G | XC6220A331MR-G | SOT95P280X120-5N | IC4 | LDO Voltage Regulators |  |  |  |  |  |  |  | LDO Voltage Regulators |  |  | 1.2mm |  | Torex | XC6220A331MR-G |  |  | 865-XC6220A331MR-G | https://www.mouser.co.uk/ProductDetail/Torex-Semiconductor/XC6220A331MR-G?qs=AsjdqWjXhJ8ZSWznL1J0gg%3D%3D

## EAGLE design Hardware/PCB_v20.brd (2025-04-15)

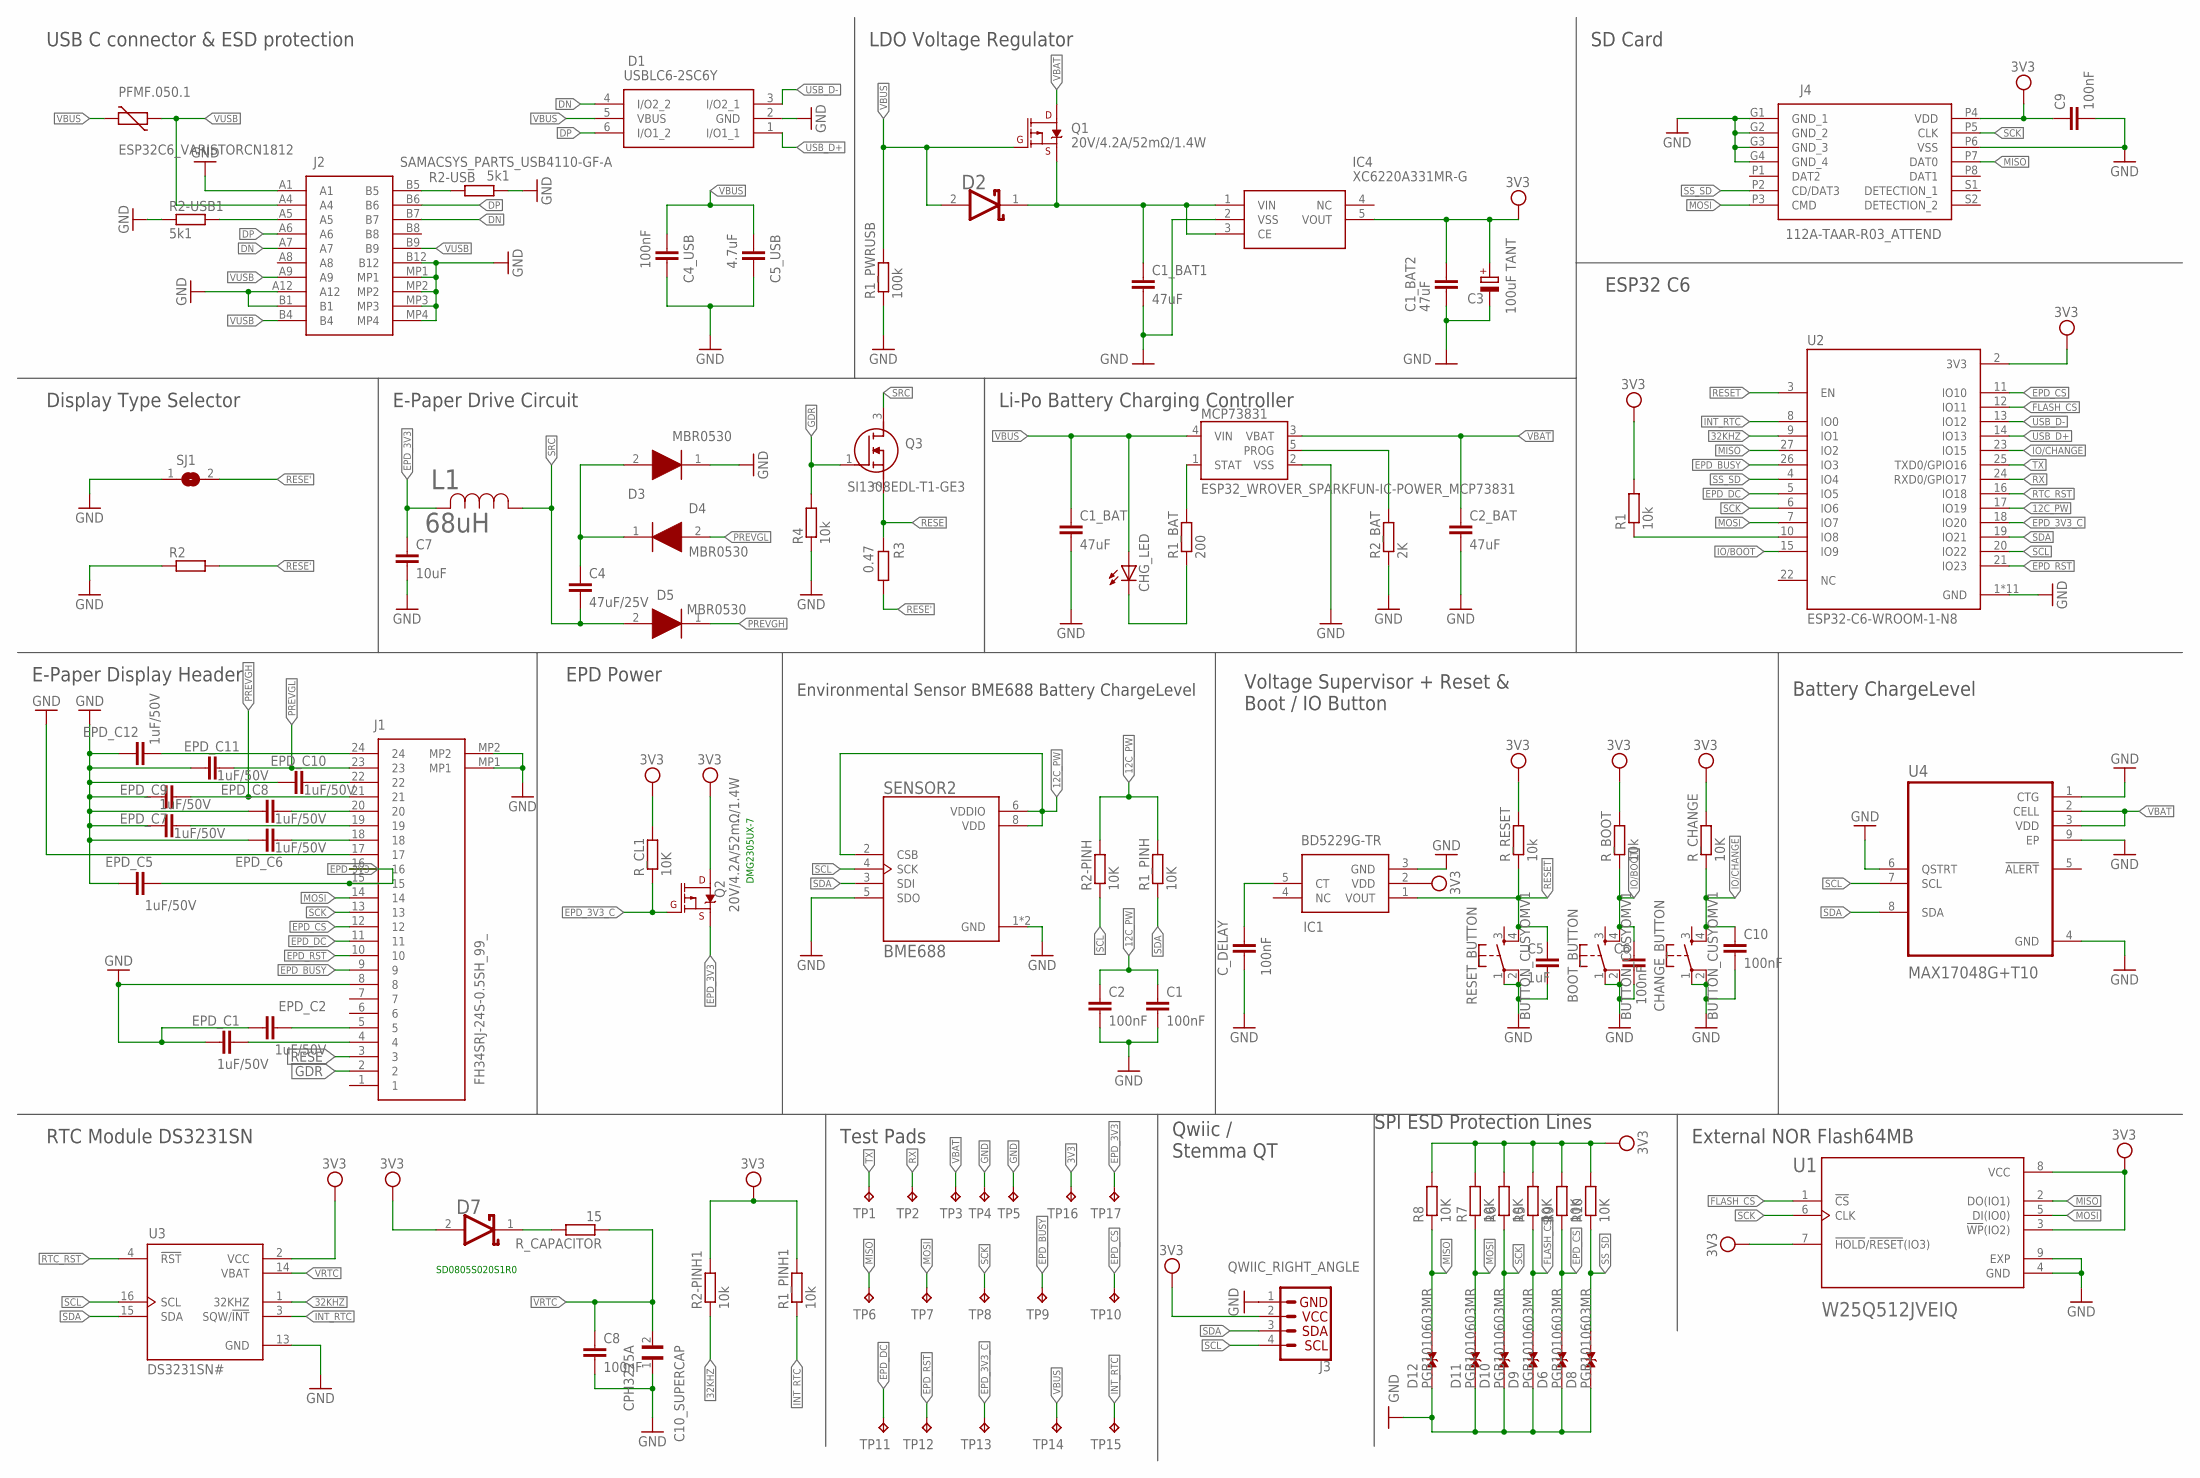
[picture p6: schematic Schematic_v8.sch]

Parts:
BOOT_BUTTON: BUTTON_CUSYOMV1; MYBUTTON
C1, C2, C4_USB, C6, C8, C9, C10: 100nF; EAGLE-LTSPICE_C0402
C1_BAT, C1_BAT1, C1_BAT2, C2_BAT: 47uF; EAGLE-LTSPICE_C0402
C3: 100uF TANT; RCL_CT3528
C4: 47uF/25V; EAGLE-LTSPICE_C0402
C5: 1uF; EAGLE-LTSPICE_C0402
C5_USB: 4.7uF; EAGLE-LTSPICE_C0402
C7: 10uF; EAGLE-LTSPICE_C0402
C10_SUPERCAP: CPH3225A; CAPCP3225X100N
CHANGE_BUTTON: BUTTON_CUSYOMV1; MYBUTTON
CHG_LED: ADAFRUIT_LEDCHIP-LED0603; ADAFRUIT_CHIP-LED0603
C_DELAY: 100nF; EAGLE-LTSPICE_C0402
D1: USBLC6-2SC6Y; SOT95P280X145-6N
D2, D7: SD0805S020S1R0; ESP32_WROVER_AVX---SD0805S020S1R0_AVX_SD0805S020S1R0_0
D3, D4, D5: MBR0530; SOD3716X135N
D6, D8, D9, D10, D11, D12: PGB1010603MR; DIOC1608X36N
EPD_C1, EPD_C2, EPD_C5, EPD_C6, EPD_C7, EPD_C8, EPD_C9, EPD_C10, EPD_C11, EPD_C12: 1uF/50V; EAGLE-LTSPICE_C0402
IC1: BD5229G-TR; SOT95P280X125-5N
IC4: XC6220A331MR-G; SOT95P280X120-5N
J1: FH34SRJ-24S-0.5SH_99_; FH34SRJ24S05SH99
J2: SAMACSYS_PARTS_USB4110-GF-A; SAMACSYS_PARTS_USB4110GFA
J3: QWIIC_RIGHT_ANGLE; JST04_1MM_RA
J4: 112A-TAAR-R03_ATTEND; 112ATAARR03ATTEND
L1: 68uH; IND_4828-WE-TPC_WRE
MCP73831: ESP32_WROVER_SPARKFUN-IC-POWER_MCP73831; ESP32_WROVER_SPARKFUN-IC-POWER_SOT23-5
PFMF.050.1: ESP32C6_VARISTORCN1812; ESP32C6_VARISTOR_CT/CN1812
Q1, Q2: 20V/4.2A/52mΩ/1.4W; ESP32_WROVER_SPARKFUN-DISCRETESEMI_SOT23-3
Q3: SI1308EDL-T1-GE3; SOT65P210X110-3N
R1, R1_PINH1, R2-PINH1, R4: 10k; ESP32_WROVER_EAGLE-LTSPICE_R0402
R1_BAT: 200; ESP32_WROVER_EAGLE-LTSPICE_R0402
R1_PINH, R2-PINH, R5, R6, R7, R8, R9, R10: 10K; ESP32_WROVER_EAGLE-LTSPICE_R0402
R1_PWRUSB: 100k; ESP32_WROVER_EAGLE-LTSPICE_R0402
R2: ESP32_WROVER_EAGLE-LTSPICE_RR0402; ESP32_WROVER_EAGLE-LTSPICE_R0402
R2-USB, R2-USB1: 5k1; ESP32_WROVER_EAGLE-LTSPICE_R0402
R2_BAT: 2K; ESP32_WROVER_EAGLE-LTSPICE_R0402
R3: 0.47; ESP32_WROVER_EAGLE-LTSPICE_R0402
RESET_BUTTON: BUTTON_CUSYOMV1; MYBUTTON
R_BOOT: 10k; ESP32_WROVER_EAGLE-LTSPICE_R0402
R_CAPACITOR: 15; ESP32_WROVER_EAGLE-LTSPICE_R0402
R_CHANGE: 10K; ESP32_WROVER_EAGLE-LTSPICE_R0402
R_CL1: 10K; ESP32_WROVER_EAGLE-LTSPICE_R0402
R_RESET: 10k; ESP32_WROVER_EAGLE-LTSPICE_R0402
SENSOR2: BME688; ESP32_WROVER_BME680_PSON80P300X300X100-8N
SJ1: SJ
TP1, TP2, TP3, TP4, TP5, TP6, TP7, TP8, TP9, TP10, TP11, TP12, TP13, TP14, TP15, TP16, TP17: TPTP20R; TP20R
U1: W25Q512JVEIQ; SON127P600X800X80-9N
U2: ESP32-C6-WROOM-1-N8; XCVR_ESP32-C6-WROOM-1-N8
U3: DS3231SN#; SOIC127P1032X265-16N
U4: MAX17048G+T10; SON50P200X200X80-9N

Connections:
3V3: C1_BAT2.1, C3.+, C9.1, D7.2 (ANODE), IC1.2 (VDD), IC4.5 (VOUT), J3.2, J4.P4 (VDD), Q2.3 (D), R1.2, R1_PINH1.2, R2-PINH1.2, R5.2, R6.2, R7.2, R8.2, R9.2, R10.2, R_BOOT.2, R_CHANGE.2, R_CL1.2, R_RESET.2, TP16.TP, U1.3 (!WP!(IO2)), U1.7 (!HOLD!/!RESET!(IO3)), U1.8 (VCC), U2.2 (3V3), U3.2 (VCC)
12C_PW: C1.1, C2.1, R1_PINH.2, R2-PINH.2, SENSOR2.2 (CSB), SENSOR2.6 (VDDIO), SENSOR2.8 (VDD), U2.16 (IO18)
32KHZ: R2-PINH1.1, U2.9 (IO1), U3.1 (32KHZ)
DN: D1.4 (I/O2_2), J2.A7, J2.B7
DP: D1.6 (I/O1_2), J2.A6, J2.B6
EPD_3V3: C7.1, EPD_C5.2, J1.15, J1.16, L1.2, Q2.2 (S), TP17.TP
EPD_3V3_C: Q2.1 (G), R_CL1.1, TP13.TP, U2.18 (IO20)
EPD_BUSY: J1.9, TP9.TP, U2.26 (IO3)
EPD_CS: D6.2, J1.12, R9.1, TP10.TP, U2.11 (IO10)
EPD_DC: J1.11, TP11.TP, U2.5 (IO5)
EPD_RST: J1.10, TP12.TP, U2.21 (IO23)
FLASH_CS: D9.2, R5.1, U1.1 (!CS), U2.12 (IO11)
GDR: J1.2, Q3.1 (G), R4.2
GND: BOOT_BUTTON.1, BOOT_BUTTON.2, C1.2, C1_BAT.2, C1_BAT1.2, C1_BAT2.2, C2.2, C2_BAT.2, C3.-, C4_USB.2, C5.2, C5_USB.2, C6.2, C7.2, C8.2, C9.2, C10.2, C10_SUPERCAP.1, CHANGE_BUTTON.1, CHANGE_BUTTON.2, C_DELAY.2, D1.2 (GND), D3.1 (K), D6.1, D8.1, D9.1, D10.1, D11.1, D12.1, EPD_C1.1, EPD_C2.1, EPD_C5.1, EPD_C6.1, EPD_C7.1, EPD_C8.1, EPD_C9.1, EPD_C10.1, EPD_C11.1, EPD_C12.1, IC1.3 (GND), IC4.2 (VSS), J1.8, J1.17, J1.MP1, J1.MP2, J2.A1, J2.A12, J2.B1, J2.B12, J2.MP1, J2.MP2, J2.MP3, J2.MP4, J3.1, J4.G1 (GND_1), J4.G2 (GND_2), J4.G3 (GND_3), J4.G4 (GND_4), J4.P6 (VSS), MCP73831.2 (VSS), R1_PWRUSB.1, R2.1, R2-USB.2, R2-USB1.1, R2_BAT.1, R4.1, RESET_BUTTON.1, RESET_BUTTON.2, SENSOR2.1 (GND), SENSOR2.5 (SDO), SENSOR2.7 (GND), SJ1.1, TP4.TP, TP5.TP, U1.4 (GND), U1.9 (EXP), U2.1 (GND), U2.28 (GND), U2.29_1 (GND), U2.29_2 (GND), U2.29_3 (GND), U2.29_4 (GND), U2.29_5 (GND), U2.29_6 (GND), U2.29_7 (GND), U2.29_8 (GND), U2.29_9 (GND), U3.13 (GND), U4.1 (CTG), U4.4 (GND), U4.6 (QSTRT), U4.9 (EP)
INT_RTC: R1_PINH1.1, TP15.TP, U2.8 (IO0), U3.3 (SQW/!INT)
IO/BOOT: BOOT_BUTTON.4, C6.1, R_BOOT.1, U2.15 (IO9)
IO/CHANGE: C10.1, CHANGE_BUTTON.4, R_CHANGE.1, U2.23 (IO15)
MISO: D12.2, J4.P7 (DAT0), R8.1, TP6.TP, U1.2 (DO(IO1)), U2.27 (IO2)
MOSI: D11.2, J1.14, J4.P3 (CMD), R7.1, TP7.TP, U1.5 (DI(IO0)), U2.7 (IO7)
unnamed: J2.A5, R2-USB1.2
unnamed: J2.B5, R2-USB.1
unnamed: C1_BAT1.1, D2.1 (CATHODE), IC4.1 (VIN), IC4.3 (CE), Q1.2 (S)
unnamed: C4.1, D3.2 (A), D4.1 (K)
unnamed: C_DELAY.1, IC1.5 (CT)
unnamed: CHG_LED.C, R1_BAT.1
unnamed: MCP73831.1 (STAT), R1_BAT.2
unnamed: MCP73831.5 (PROG), R2_BAT.2
unnamed: EPD_C12.2, J1.24
unnamed: EPD_C10.2, J1.22
unnamed: EPD_C7.2, J1.19
unnamed: EPD_C8.2, J1.20
unnamed: D7.1 (CATHODE), R_CAPACITOR.2
unnamed: EPD_C6.2, J1.18
unnamed: R1.1, U2.10 (IO8)
unnamed: EPD_C2.2, J1.5
unnamed: EPD_C1.2, J1.4
PREVGH: D5.1 (K), EPD_C9.2, J1.21
PREVGL: D4.2 (A), EPD_C11.2, J1.23
RESE: J1.3, Q3.2 (S), R3.2
RESE': R2.2, R3.1, SJ1.2
RESET: C5.1, IC1.1 (VOUT), RESET_BUTTON.4, R_RESET.1, U2.3 (EN)
RTC_RST: U2.17 (IO19), U3.4 (!RST)
RX: TP2.TP, U2.24 (RXD0/GPIO17)
SCK: D10.2, J1.13, J4.P5 (CLK), R6.1, TP8.TP, U1.6 (CLK), U2.6 (IO6)
SCL: J3.4, R2-PINH.1, SENSOR2.4 (SCK), U2.20 (IO22), U3.16 (SCL), U4.7 (SCL)
SDA: J3.3, R1_PINH.1, SENSOR2.3 (SDI), U2.19 (IO21), U3.15 (SDA), U4.8 (SDA)
SRC: C4.2, D5.2 (A), L1.1, Q3.3 (D)
SS_SD: D8.2, J4.P2 (CD/DAT3), R10.1, U2.4 (IO4)
TX: TP1.TP, U2.25 (TXD0/GPIO16)
USB_D+: D1.1 (I/O1_1), U2.14 (IO13)
USB_D-: D1.3 (I/O2_1), U2.13 (IO12)
VBAT: C2_BAT.1, MCP73831.3 (VBAT), Q1.3 (D), TP3.TP, U4.2 (CELL), U4.3 (VDD)
VBUS: C1_BAT.1, C4_USB.1, C5_USB.1, CHG_LED.A, D1.5 (VBUS), D2.2 (ANODE), MCP73831.4 (VIN), PFMF.050.1.2, Q1.1 (G), R1_PWRUSB.2, TP14.TP
VRTC: C8.1, C10_SUPERCAP.2, R_CAPACITOR.1, U3.14 (VBAT)
VUSB: J2.A4, J2.A9, J2.B4, J2.B9, PFMF.050.1.1

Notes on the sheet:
DMG2305UX-7
SD0805S020S1R0
USB C connector & ESD protection
LDO Voltage Regulator
SD Card
Display Type Selector
E-Paper Drive Circuit
Li-Po Battery Charging Controller
ESP32 C6
E-Paper Display Header
EPD Power
Environmental Sensor BME688 Battery ChargeLevel
Voltage Supervisor + Reset & Boot / IO Button
Battery ChargeLevel
External NOR Flash64MB
SPI ESD Protection Lines
Qwiic / Stemma QT
Test Pads
RTC Module DS3231SN

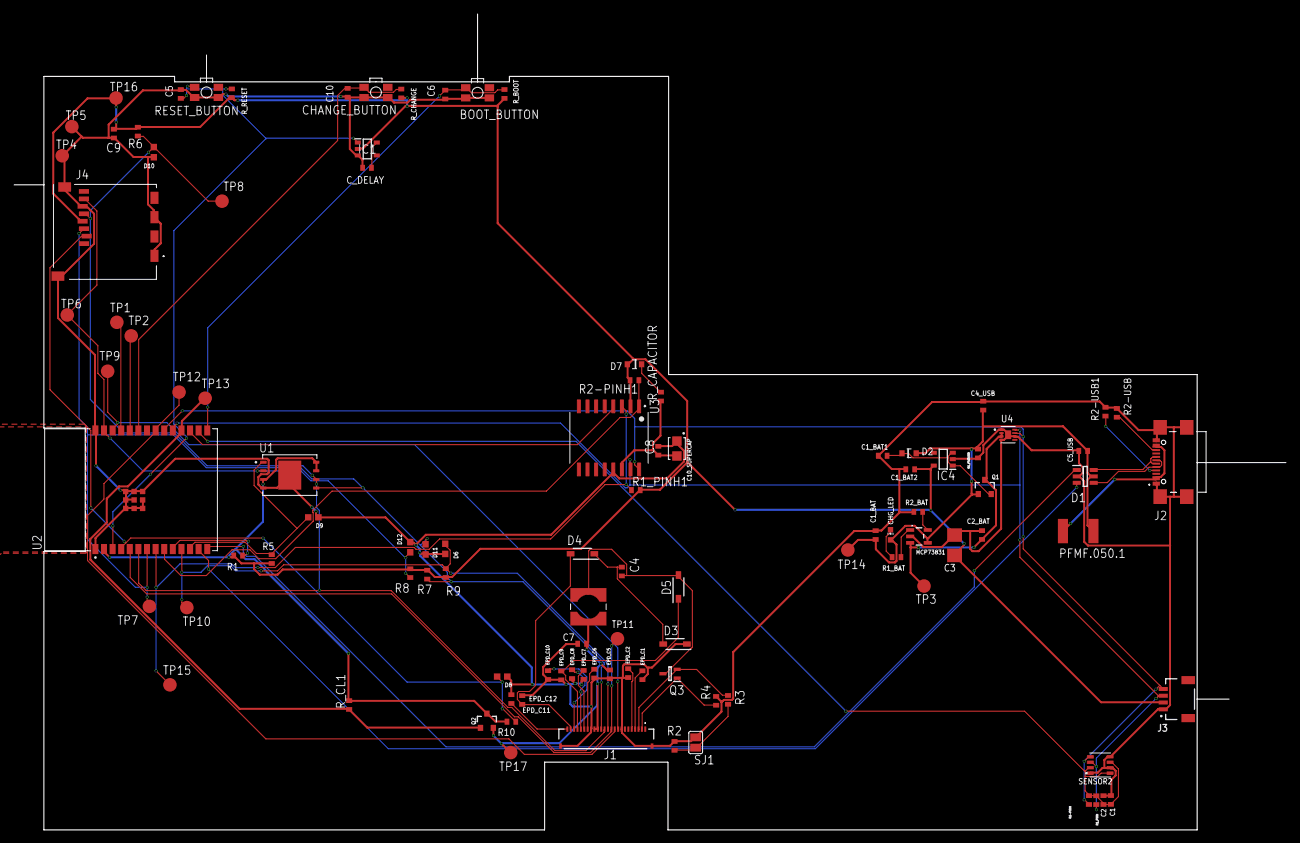
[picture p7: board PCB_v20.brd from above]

Board: 2 copper layers, 170.2 x 111.2 mm, 103 parts (0 on the bottom side), 55 nets.

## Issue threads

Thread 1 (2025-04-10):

Plan de masa

edwardnita, 2025-04-10:
Pe layer-ul bottom al planului de masa din apropierea modulului ESP32 (dreapta, jos) exista o zona ce poate fi imbunatatita prin aplicarea Via Stitching.

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

Closed 2025-04-15.

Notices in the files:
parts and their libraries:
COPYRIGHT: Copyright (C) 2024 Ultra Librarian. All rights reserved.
